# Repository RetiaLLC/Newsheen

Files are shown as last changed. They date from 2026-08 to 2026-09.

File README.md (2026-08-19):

# Newsheen

An **ESP32-S3 LED controller board** and 3D-printed base that turn a translucent 130 mm silicone
lamp into a smart RGB light — 8 addressable LEDs, an IR remote, USB-C, and an optional LoRa radio.

This repo carries the **3D files, the pinout, and firmware** so you can print the base, assemble a
board, and light it up. (KiCad design sources are kept in a separate private repo.)

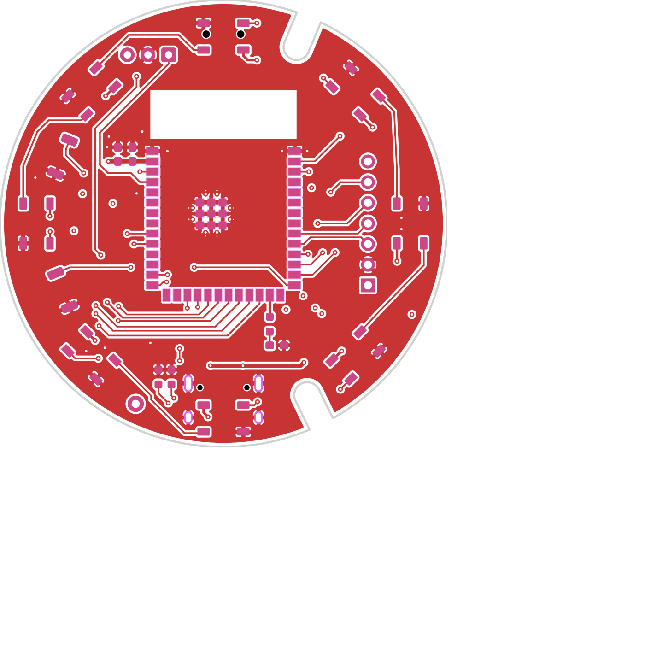
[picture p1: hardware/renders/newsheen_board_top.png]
Newsheen board


## What's here

```
hardware/
  pinout.md                    basic GPIO map + build notes
  3d/board/                    board 3D models (STL) — for enclosure/fitment design
  3d/printed-base/             the 3D-printed base: base + button + retaining ring (v4)
firmware/
  simple-led-remote/           offline IR-remote LED controller (source + ready-to-flash factory bin)
  recipes/wledkitty.md         full firmware: WLED + audio-reactive + IR + Wi-Fi web UI
```

## Quick start

1. **Print the base** — `hardware/3d/printed-base/` (base + button + retaining ring, v4). Drop in a
   `98455A367` internal retaining ring (STEP included for reference).
2. **Assemble** — seat the board, connect USB-C. See `hardware/pinout.md` for the IR-receiver and
   LED build notes.
3. **Flash** the simple LED remote:
   ```bash
   esptool --chip esp32s3 write-flash 0x0 firmware/simple-led-remote/dist/newsheen-simple-led-remote.factory.bin
   ```
4. **Point the 21-key IR remote** and press a button — colors, white, brightness ±, effects, on/off.
   Firmware details: `firmware/simple-led-remote/README.md`.

## Firmware

Two ways to run the puck:

- **Simple LED Remote** (above) — tiny, offline, no Wi-Fi. Point the 21-key remote and go.
- **WLEDkitty** — the full experience: the 8 LEDs are **sound-reactive** through the onboard I²S
  mic, the same IR remote works, and you get the complete WLED web UI over a built-in Wi-Fi AP.
  Boots into the Freqwave audio visualizer. Browser-flash it at
  **[scriptkitty.sh](https://scriptkitty.sh)**, or see
  [`firmware/recipes/wledkitty.md`](firmware/recipes/wledkitty.md).
- **[Newsheen Radio](https://github.com/RetiaLLC/NewsheenRadio)** — turns the puck into an
  internet radio. Streams MP3 and AAC over HTTP and HTTPS, searches tens of thousands of
  stations, and plots them on a globe you can spin and tap to tune. The 8 LEDs run 15 effects,
  4 of them driven by a live frequency analysis of the audio. Requires a **MAX98357A amplifier
  and speaker wired to the J3 header** (see that repo for the pinout). Browser-flash it at
  **[scriptkitty.sh](https://scriptkitty.sh/#newsheen)**.

## Board at a glance

- **ESP32-S3-WROOM-1**, 16 MB flash / 2 MB PSRAM (N16R2), native USB-C
- **8× WS2812B** addressable LEDs (GPIO16, via a 5 V level shifter)
- **IR receiver** (VS1838B) on GPIO4
- User button, status LED, sensor/mic header (I²C + I²S)
- Optional **LoRa** (Seeed Wio-SX1262)

Full map: [`hardware/pinout.md`](hardware/pinout.md).

## License

Hardware/3D files: CC BY-SA 4.0. Firmware: MIT. © RetiaLLC.

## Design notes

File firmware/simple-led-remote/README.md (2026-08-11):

# Newsheen — Simple LED Remote firmware

A tiny, self-contained firmware that lets the bundled **21-key IR remote** drive the Newsheen
board's 8 addressable LEDs. No Wi-Fi, no app — point the remote and press a button.

## Flash it

Easiest: flash the pre-built image with [esptool](https://github.com/espressif/esptool) or any
ESP32 web flasher:

```bash
esptool --chip esp32s3 write-flash 0x0 dist/newsheen-simple-led-remote.factory.bin
```

Or build from source: `pio run -e newsheen-led-remote` (PlatformIO).

## What the buttons do

| Button | Action | Button | Action |
|---|---|---|---|
| ON / OFF | LEDs on / off | R, G, B | red / green / blue |
| + / − | brightness up / down | W | white |
| SMOOTH | flowing rainbow | color grid | 12 preset colors |
| FLASH | strobe | 30MIN / 60MIN | sleep timer |

Boots to a warm white. Holding **+ / −** ramps brightness.

## Requirements

- IR receiver: a **VS1838B** (or any GND-in-the-middle 38 kHz demodulating receiver) on **GPIO4**,
  installed with **OUT in the square pad**.
- LEDs: 8× WS2812B on **GPIO16**. On v2 boards, tie the LED level-shifter DIR pin to **+3V3** so
  the LEDs render (see `../../hardware/pinout.md`).

Codes are the standard NEC `0xFF…` 21-key RGB-remote set (address `0x00`); the same codes work
with WLED's built-in "21-key" IR remote type if you later run WLED on the board.

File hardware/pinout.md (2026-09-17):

# Newsheen — pinout & build notes

**MCU:** Espressif **ESP32-S3-WROOM-1**, **N16R2** (16 MB quad flash, 2 MB quad PSRAM).
Round ~55 mm PCB. USB-C (native USB). Designed to sit in the 3D-printed base (`../hardware/3d`).

> Verify flash/PSRAM from the real module with `esptool flash-id` before building — the assembled
> part is the **quad-PSRAM N16R2**. An octal-PSRAM (`…R8`) part would consume GPIO33–37 and break
> the I²C / I²S header.

## GPIO map

| Function | GPIO | Notes |
|---|---|---|
| **Addressable LEDs** | **16** | 8× WS2812B, via a 3V3→5V level shifter |
| **IR receiver (OUT)** | **4** | VS1838B (GND-middle, 38 kHz); OUT → the square pad |
| User button | 17 | active-low, pulled up |
| BOOT | 0 | strapping |
| Reset | EN | — |
| Status LED | 48 | plain LED |
| Buzzer pad | 15 | not populated by default |
| USB D− / D+ | 19 / 20 | native USB |
| I²C SDA / SCL | 35 / 36 | sensor header, 5.1 kΩ pull-ups to 3V3 |
| I²S WS / SCK / SD | 37 / 38 / 39 | sensor header (external mic) |
| Battery sense / charge | 1 / 2 | test points |
| **LoRa** (Wio-SX1262) | NSS 10, MOSI 11, MISO 12, SCK 13, RF_SW 14, NRST 9, DIO1 21, BUSY 47 | 3V3; ANT = wire-antenna pad |

## Build notes (v2 boards)

- **LEDs:** the WS2812 level-shifter's direction pin must be tied **HIGH (+3V3)** for LED data to
  reach the strip. (Corrected in later revisions.)
- **IR:** the receiver footprint expects a **GND-in-the-middle** part (VS1838B / TSOP38238). Install
  with the **OUT/signal leg in the square pad** (toward the module); VCC and GND take the outer pads.
  Breakout-style receivers with VCC in the middle will not work.

## Power & battery

Stock power is **USB-C only**. The 3.3 V rail comes from an onboard regulator fed by the 5 V bus,
and there is no battery-charging circuit on the board.

| Pad | Purpose |
|---|---|
| `N-EXT` | external **regulated 5 V** input (corner pad) |
| `GND` | ground return, beside `N-EXT` |
| `JP1` | bridge to tie `N-EXT` to the 5 V bus (silk: `SOLDER JP1 FOR EXT PWR`) |
| `3V3` | regulator **output**. Never drive power into this pad. |

### Running on external 5 V, or adding a battery (advanced)

The Newsheen is designed to stay plugged in over USB-C. It has no battery circuit of its own, and a
battery is not recommended for beginners: it is an advanced mod you take on at your own risk.

If you want one anyway, external power must be a **regulated 5 V**: a bare 3.7 V LiPo browns the
board out. Run a cell through a charge-and-boost board set to 5 V, then feed it into the corner
`N-EXT` pad and a `GND` pad, and bridge the `JP1` jumper beside it (silk: `SOLDER JP1 FOR EXT PWR`).

A known-good combo is a **TP4056** charger (LiPo charge + protection) into an **MT3608** boost
converter trimmed to **5.0 V**, with the boost output going to `N-EXT`/`GND`.

- **Never put 5 V or a raw battery on the `3V3` pad.** That pad is the regulator's output;
  back-feeding it can damage the board.
- Charge the cell through the charger board's own USB, not the Sheen's USB-C.
- Keep the boost output at 5.0 V. Higher voltages stress the regulator and the WS2812 level shifter.

Part picks and a wiring photo live on the getting-started site
([catlamp.site](https://catlamp.site)) and in the [Retia Discord](https://discord.gg/cJHNswdSTz).

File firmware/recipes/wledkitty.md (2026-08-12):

# WLEDkitty on the Newsheen puck

The full-featured firmware for the Newsheen puck: [WLED](https://github.com/wled/WLED) with a
Retia personality. Drives the 8 addressable LEDs, reacts to sound through the onboard I2S mic,
takes commands from a 21-key IR remote, and serves the complete WLED web UI over its own Wi-Fi
AP. Boots straight into the **Freqwave** audio visualizer at full brightness.

## Flash it (easiest)

Browser-flash at **[scriptkitty.sh](https://scriptkitty.sh)** — no tools needed. Or grab
`wledkitty-newsheen-puck.factory.bin` from this repo's latest release and:

```bash
esptool --chip esp32s3 write-flash 0x0 wledkitty-newsheen-puck.factory.bin
```

After flashing:
- It boots into **Freqwave** — play music or talk near it and the cat lamp dances to the sound.
  (Audio effects are *dark in a silent room* by design; that's the effect resting, not a fault.)
- Point the **21-key IR remote** at it for colors, white, brightness, and effects.
- Join its **`WLED-<id>`** Wi-Fi (password `wled1234`) and open `http://4.3.2.1` for the full
  web UI + effect picker (pick any ♪/♫ effect for other sound-reactive looks).

## Build from source

Source: **[RetiaLLC/WLEDkitty](https://github.com/RetiaLLC/WLEDkitty)** (branch `wledkitty`),
a WLED fork carrying the Retia device build envs. The puck's env is `newsheen-puck-audio`.

```bash
git clone -b wledkitty https://github.com/RetiaLLC/WLEDkitty && cd WLEDkitty
pio run -e newsheen-puck-audio          # Python 3.12/3.13 (the ESP32 toolchain rejects 3.14+)

# merge a 16 MB DIO factory image
BOOT_APP0=$(find ~/.platformio/packages/framework-arduinoespressif32*/tools/partitions/boot_app0.bin | head -1)
esptool --chip esp32s3 merge-bin -o wledkitty-newsheen-puck.factory.bin \
  --flash-mode dio --flash-freq 80m --flash-size 16MB \
  0x0 .pio/build/newsheen-puck-audio/bootloader.bin \
  0x8000 .pio/build/newsheen-puck-audio/partitions.bin \
  0xE000 "$BOOT_APP0" \
  0x10000 .pio/build/newsheen-puck-audio/firmware.bin
```

## Why this env — key build flags

| Flag | What it does |
|---|---|
| `WLED_BOOTUPDELAY=2500` | Fixes a **softAP boot-settle race**: without it the release build beacons `WLED-AP` but *no client can associate* (the AP comes up before the board settles). Bench-verified 20/20 vs 0/8. |
| `WLED_AP_SSID_UNIQUE` | Per-device AP name (`WLED-<last-3-MAC-bytes>`) so a fleet of units never collide on one SSID. Pass stays `wled1234`. |
| `SR_DMTYPE=3` + `I2S_WSPIN=37 I2S_CKPIN=38 I2S_SDPIN=39` | SPH0645-class I2S mic on the sensor header. Mic type is runtime-switchable (Settings → Usermods) for INMP441 / ICS-43434, etc. |
| `WLED_I2S_SEL_GND=36` | Drives GPIO36 low to ground the mic's **SEL** pin (it lands on the SCL pad when the SPH0645 plugs straight into the header) → left channel, **no rewiring**. |
| `IRPIN=4` + `IRTYPE=5` | 21-key RGB IR remote on GPIO4. |
| `DEFAULT_MODE=137` + `DEFAULT_BOOT_FX=137` + `WLED_DEFAULT_BRIGHTNESS=255` | Boots the **Freqwave** audio visualizer at 100 %. |

Mic sourcing and the sensor-header pinout: see [`hardware/pinout.md`](../../hardware/pinout.md).

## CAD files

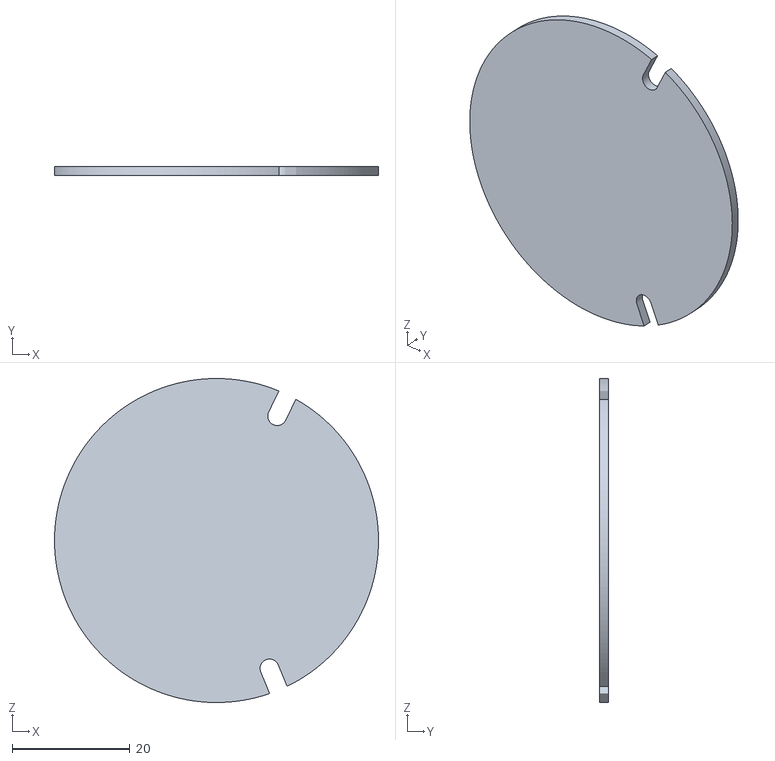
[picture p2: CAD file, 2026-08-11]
hardware/3d/board/newsheen_board_outline.stl
55.0 x 1.60 x 55.0

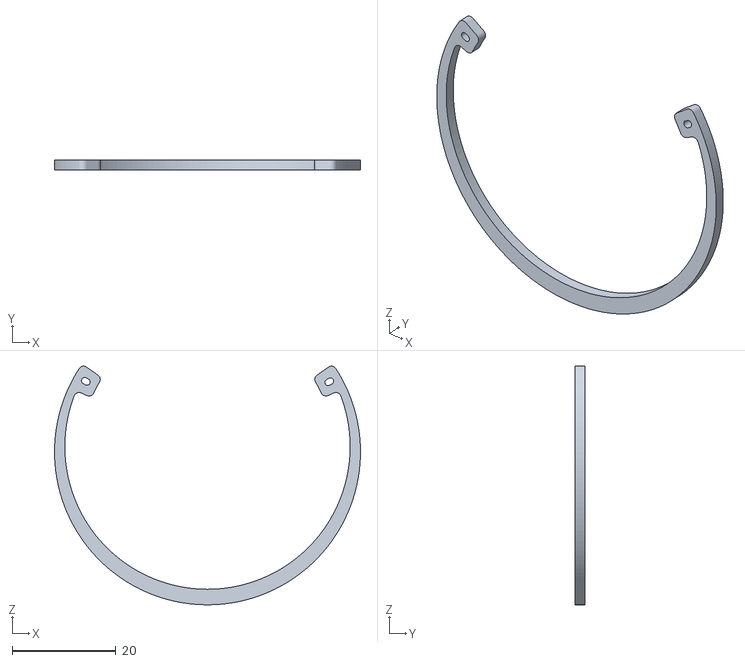
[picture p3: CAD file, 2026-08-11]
hardware/3d/printed-base/newsheen_base_retaining_ring_v4.stl
59.0 x 1.90 x 46.0

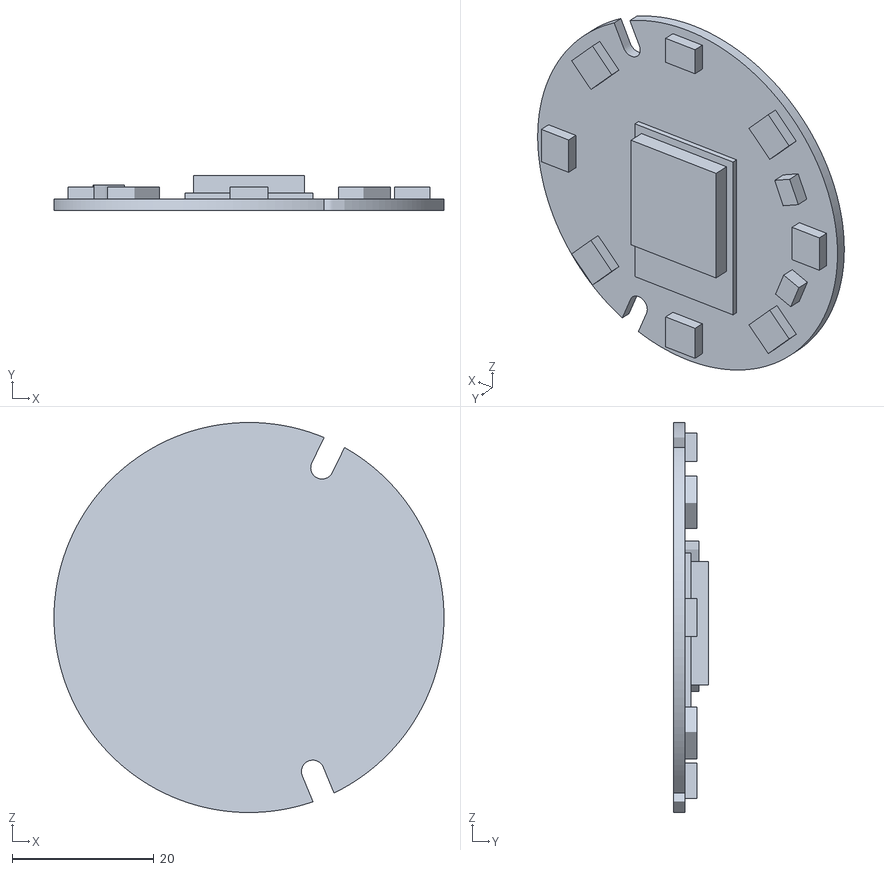
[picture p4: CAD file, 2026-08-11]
hardware/3d/board/newsheen_board_with_top_components.stl
55.0 x 4.89 x 55.0

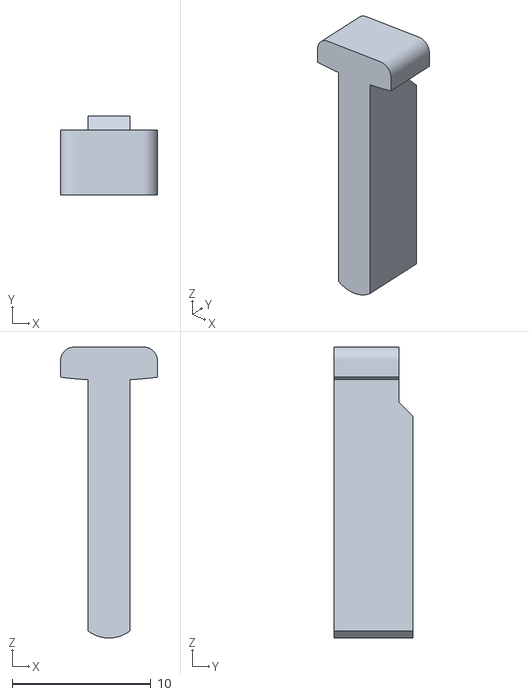
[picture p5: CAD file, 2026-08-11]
hardware/3d/printed-base/newsheen_base_button_v4.stl
7.00 x 5.70 x 21.0

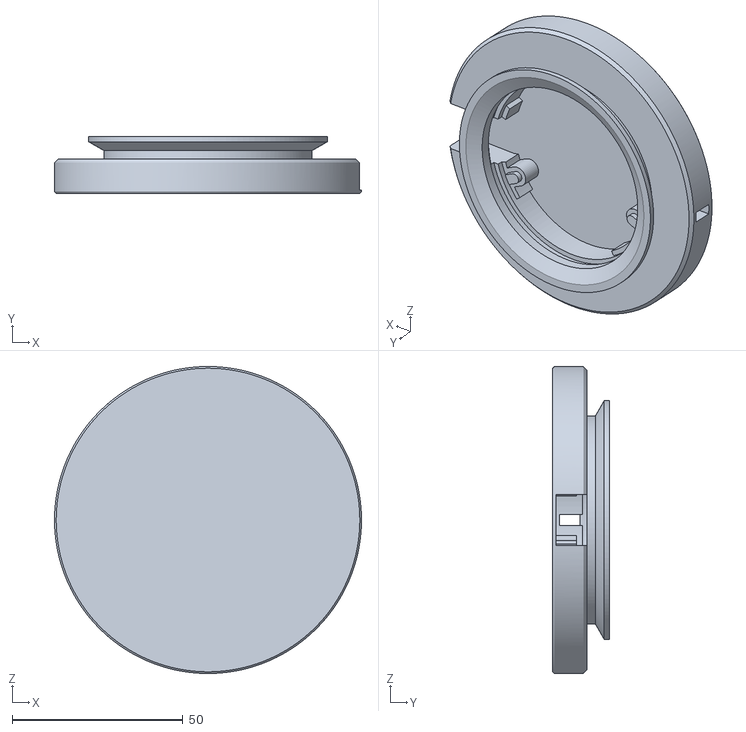
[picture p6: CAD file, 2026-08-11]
hardware/3d/printed-base/newsheen_base_v4.stl
90.0 x 16.6 x 90.0

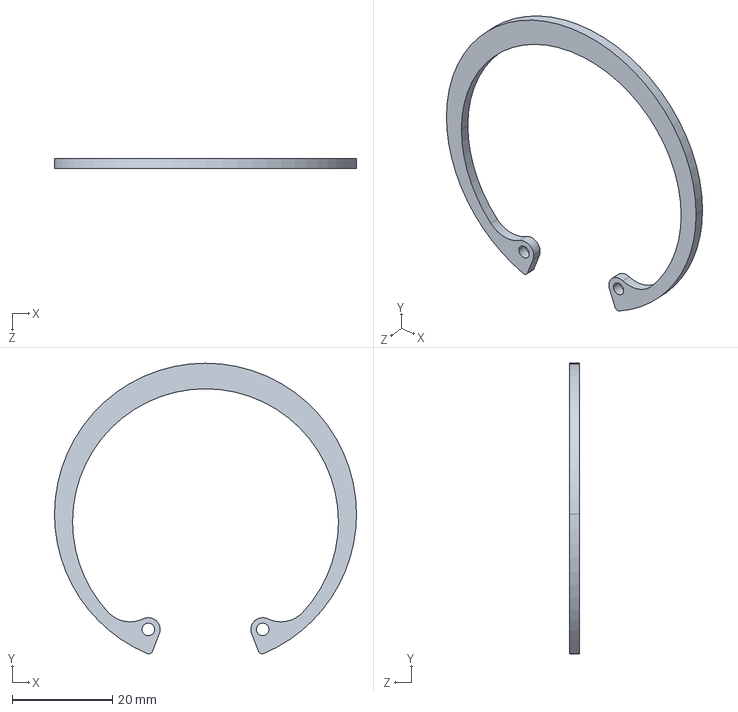
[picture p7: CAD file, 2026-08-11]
hardware/3d/printed-base/hardware_retaining_ring_mcmaster_98455A367.step
60.2 x 57.9 x 2.00 mm

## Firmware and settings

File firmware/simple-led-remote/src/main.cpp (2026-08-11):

// Newsheen Simple LED Remote — standalone IR-remote LED controller for the Newsheen board (ESP32-S3)
//   IR receiver (VS1838B) on GPIO4, 8x WS2812B on GPIO16 (via the 3V3->5V level shifter).
//   Maps the 21-key RGB remote's NEC codes to colors / white / on-off / brightness / effects.
//   Build notes: install the VS1838B with OUT in the SQUARE pad; on v2 boards tie the LED
//   level-shifter DIR pin high (+3V3) so the LEDs render. See hardware/pinout.md.
//   IRrecv OWNS GPIO4 (no manual pin ISR). 64-bit codes printed via resultToHexidecimal.
#include <Arduino.h>
#include <IRremoteESP8266.h>
#include <IRrecv.h>
#include <IRutils.h>
#include <Adafruit_NeoPixel.h>

#define IR_PIN   4
#define LED_PIN  16
#define NLED     8

IRrecv irrecv(IR_PIN, 1024, 15, true);
decode_results results;
Adafruit_NeoPixel strip(NLED, LED_PIN, NEO_GRB + NEO_KHZ800);

// ---- captured RGB-remote codes ----
#define C_ON        0xFFA25D
#define C_OFF       0xFF629D
#define C_30MIN     0xFFE21D
#define C_SMOOTH    0xFF22DD
#define C_FLASH     0xFF02FD
#define C_60MIN     0xFFC23D
#define C_UP        0xFFE01F
#define C_DOWN      0xFFA857
#define C_W         0xFF906F
#define C_R         0xFF6897
#define C_G         0xFF9867
#define C_B         0xFFB04F
#define C_REDORANGE 0xFF30CF
#define C_GREEN2    0xFF18E7
#define C_INDIGO    0xFF7A85
#define C_ORANGE    0xFF10EF
#define C_CYAN      0xFF38C7
#define C_PURPLE    0xFF5AA5
#define C_YELLOW    0xFF42BD
#define C_LTBLUE    0xFF4AB5
#define C_PINK      0xFF52AD
#define C_REPEAT    0xFFFFFFFFFFFFFFFFULL   // NEC "button held" repeat frame

enum Mode { SOLID, SMOOTH, FLASH };
Mode mode = SOLID;
bool on = true;
uint8_t bright = 160;
uint8_t curR = 255, curG = 200, curB = 120;   // boot = warm white
uint64_t lastCode = 0;
uint32_t offAtMs = 0, lastAnim = 0;
uint16_t hue = 0; bool flashPhase = false;

void setSolid(uint8_t r, uint8_t g, uint8_t b) { curR=r; curG=g; curB=b; mode=SOLID; on=true; }

void renderSolid() {
  strip.setBrightness(bright);
  uint32_t c = on ? strip.Color(curR, curG, curB) : 0;
  for (int i = 0; i < NLED; i++) strip.setPixelColor(i, c);
  strip.show();
}

const char* handle(uint64_t code) {
  switch (code) {
    case C_ON:        on=true;  renderSolid(); return "ON";
    case C_OFF:       on=false; renderSolid(); return "OFF";
    case C_W:         setSolid(255,255,255); renderSolid(); return "WHITE";
    case C_R:         setSolid(255,0,0);     renderSolid(); return "RED";
    case C_G:         setSolid(0,255,0);     renderSolid(); return "GREEN";
    case C_B:         setSolid(0,0,255);     renderSolid(); return "BLUE";
    case C_REDORANGE: setSolid(255,80,0);    renderSolid(); return "RED-ORANGE";
    case C_GREEN2:    setSolid(90,255,0);    renderSolid(); return "LIME";
    case C_INDIGO:    setSolid(50,0,255);    renderSolid(); return "INDIGO";
    case C_ORANGE:    setSolid(255,140,0);   renderSolid(); return "ORANGE";
    case C_CYAN:      setSolid(0,255,200);   renderSolid(); return "CYAN";
    case C_PURPLE:    setSolid(150,0,255);   renderSolid(); return "PURPLE";
    case C_YELLOW:    setSolid(255,210,0);   renderSolid(); return "YELLOW";
    case C_LTBLUE:    setSolid(0,150,255);   renderSolid(); return "LT-BLUE";
    case C_PINK:      setSolid(255,0,120);   renderSolid(); return "PINK";
    case C_UP:        bright = (bright>=235)?255:bright+20; on=true; renderSolid(); return "BRIGHT+";
    case C_DOWN:      bright = (bright<=25)?5:bright-20;            renderSolid(); return "BRIGHT-";
    case C_SMOOTH:    mode=SMOOTH; on=true; return "SMOOTH";
    case C_FLASH:     mode=FLASH;  on=true; return "FLASH";
    case C_30MIN:     offAtMs = millis()+30UL*60*1000; return "TIMER 30m";
    case C_60MIN:     offAtMs = millis()+60UL*60*1000; return "TIMER 60m";
    default:          return nullptr;
  }
}

void setup() {
  Serial.begin(115200);
  delay(1200);
  Serial.println("\n\n=== Newsheen IR color control (GPIO4 rx / GPIO16 leds) ===");
  strip.begin();
  irrecv.enableIRIn();
  renderSolid();   // boot: warm white, on
}

void loop() {
  if (irrecv.decode(&results)) {
    uint64_t c = results.value;
    if (c == C_REPEAT) {                       // held button: only ramp brightness
      if (lastCode==C_UP || lastCode==C_DOWN) { const char* a=handle(lastCode); Serial.printf("  repeat -> %s (bri=%d)\n", a, bright); }
    } else {
      const char* act = handle(c);
      lastCode = c;
      Serial.printf("RX code="); Serial.print(resultToHexidecimal(&results));
      Serial.printf("  -> %s\n", act ? act : "(unmapped)");
    }
    irrecv.resume();
  }

  uint32_t now = millis();
  if (offAtMs && now > offAtMs) { on=false; offAtMs=0; renderSolid(); Serial.println("  sleep timer -> OFF"); }

  if (on && mode==SMOOTH && now-lastAnim > 18) {
    lastAnim = now; hue += 220; strip.setBrightness(bright);
    for (int i=0;i<NLED;i++) strip.setPixelColor(i, Adafruit_NeoPixel::ColorHSV(hue + i*(65536/NLED)));
    strip.show();
  } else if (on && mode==FLASH && now-lastAnim > 260) {
    lastAnim = now; flashPhase = !flashPhase; strip.setBrightness(bright);
    uint32_t c = flashPhase ? strip.Color(curR,curG,curB) : 0;
    for (int i=0;i<NLED;i++) strip.setPixelColor(i, c);
    strip.show();
  }
}

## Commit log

2026-08-11 Newsheen v1.0.0 — 3D files, pinout, and Simple LED Remote firmware
    Board 3D models + v4 3D-printed base (base/button/retaining ring), basic pinout + build notes, and the IR-remote LED controller firmware (source + factory bin). KiCad design sources intentionally exc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
    [hardware_retaining_ring_mcmaster_98455A367.step, newsheen_base_button_v4.stl, newsheen_base_retaining_ring_v4.stl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]
2026-09-17 hardware/pinout.md: add Power & battery section (pad table + external-5V/battery mod) (#1)
